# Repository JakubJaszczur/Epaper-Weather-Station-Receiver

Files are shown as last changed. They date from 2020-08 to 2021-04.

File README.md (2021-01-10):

## Epaper Weather Station Receiver

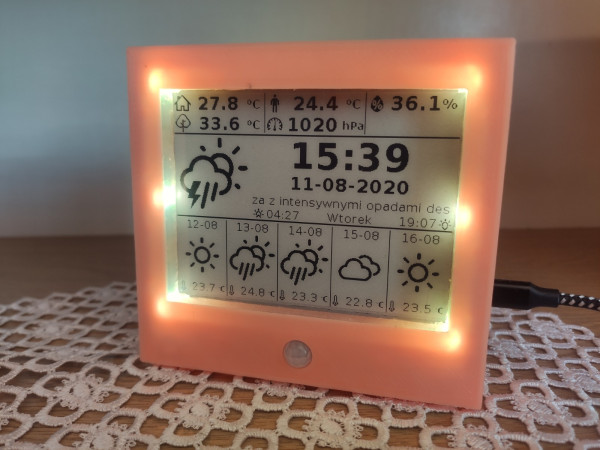
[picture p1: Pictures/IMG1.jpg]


### 1. Introduction

The project is a part of bigger IOT system. Weather Station receiver measures basic parameters, such as temperature, pressure, humidity, but also CO2, TVOC level. Other parameters, like outside temperature, weather forecast can be received by MQTT and displayed on 4.2" Epaper display.

### 2. Features

- 4.2" E-paper display with additional NeoPixel backlight
- Backlight colour depends on CO<sub>2</sub> in room
- Li-Ion battery as backup PS
- Additional fan for better air flow
- Temperature, humidity, pressure measurements
- CO<sub>2</sub>, TVOC level measurements
- PIR sensor
- Time, date, sunrise/sunset time display
- Current weather forecast with description
- Weather forecast for next 5 days
- Outside temperature, felt temperature display
- All displayed parameters/icons can be easily changed
- All not measured parameters are send to/from weather station by MQTT

### 3. Bill of Materials

Main components:

| Device  		 | Description 	 | Price		  | 
| --- | --- |---|
| ESP32 DEVKIT V1 | Main IC |	$3.50 |
| BME280 | Temperature, humidity, pressure sensor  |	$2.10 |
| MCP9808 | High accuracy temperature sensor | $0.75 |
| CCS811 | CO<sub>2</sub>, TVOC sensor | $5.89 |
| HC-SR505 | PIR sensor (AM312) | $1.15 |
| J5019 | Battery charger with DC-DC converter | $0.69 |
| 4.2" Epaper | Waveshare E-paper Display Module | $28.47 |
| 25mm fan | 5V fan (25x25x7mm) | $1.22 |
| SK6812 | RGBW NeoPixel LED | $0.25 |
| 1000mAh Li-Ion  | Battery | $2.50 |
| PCB | Custom PCB | |
| Housing | Custom housing (3D printed) | |

### 4. Libraries

- [GxEPD](https://github.com/ZinggJM/GxEPD "GxEPD")
- [Adafruit GFX](https://github.com/adafruit/Adafruit-GFX-Library "Adafruit_GFX")
- [PubSubClient](https://github.com/knolleary/pubsubclient "PubSubClient")
- [ArduinoJson](https://github.com/bblanchon/ArduinoJson "ArduinoJsonD")
- [Adafruit MCP9808](https://github.com/adafruit/Adafruit_MCP9808_Library "Adafruit_MCP9808")
- [Adafruit BME280](https://github.com/adafruit/Adafruit_BME280_Library "Adafruit_BME280")
- [Adafruit Sensor](https://github.com/adafruit/Adafruit_Sensor "Adafruit_Sensor")
- [Adafruit CCS811](https://github.com/adafruit/Adafruit_CCS811 "Adafruit_CCS811")
- [Adafruit NeoPixel](https://github.com/adafruit/Adafruit_NeoPixel "Adafruit_NeoPixel")

### 5. Getting Started

To run Weather Station, user should change some settings in data.h file:

Basic WiFi settings
```
// WiFi Settings
const char* ssid = "YOUR_SSID";
const char* password = "YOUR_PASSWORD";
```

Choose, how many NeoPixel LEDs you want to use. You can solder up to 10 LEDs. If you use less than 10, you should make shorts everywhere, where you do not use LEDs (Designators R2 to R7)
```
// NeoPixel settings
 ...
#define LED_COUNT   6       // No of LEDs
```

Uncomment, if you use MQTT user and password
```
// MQTT Settings
const char* mqtt_server = "MQTT_SERVER_IP";
//const char* mqtt_user = "MQTT_USER";
//const char* mqtt_password = "MQTT_PASSWORD";
```

You can adjust, how often display will be refreshed, and how often presence will be checked using PIR sensor (it also defines minimum backlight time)
```
// Refresh time in seconds
#define REFRESH_TIME	30
#define PRESENCE_TIME   5
```

Define altitude of your home (for pressure measurements)
```
// Sensors config data
#define ALTITUDE        515.0 //define altitude of location
```

Define MQTT Publish and Subscribe topics compatible with your server
```
// MQTT Input topics
#define TEMPOUT_TOPIC       "home/weatherstation/tempout"
#define TIME_TOPIC          "basic/time/time"
#define DATE_TOPIC          "basic/time/date"
#define SUNRISE_TOPIC       "conditions/weather/sunrise"
#define SUNSET_TOPIC        "conditions/weather/sunset"
#define DESCRIPTION_TOPIC   "conditions/weather/description"
#define WEEKDAY_TOPIC       "basic/time/day"
#define WEATHER_ICON_TOPIC  "conditions/weather/icon"
#define FELT_TEMP_TOPIC     "conditions/weather/tempfeel"
#define FORECAST1_TOPIC     "forecast1"
#define FORECAST2_TOPIC     "forecast2"
#define FORECAST3_TOPIC     "forecast3"
#define FORECAST4_TOPIC     "forecast4"
#define FORECAST5_TOPIC     "forecast5"

// MQTT Output topics
#define PUBLISH_TOPIC       "home/station"
```

### 6. Description

The main functionality of Weather Station is to measure inside conditions and display parameters on Epaper display.

#### Measurements
- <b>Temperature:</b> measured by MCP9808 to ensure high accuracy (0,25&ordm;C)
- <b>Humidity, Pressure:</b> measured by BME280
- <b>CO<sub>2</sub>, TVOC:</b> measured by CCS811
- <b>Presence:</b> measured by HC-SR505 PIR sensor, used to detect presence and to switch ON backlight
- <b>Other:</b> battery voltage can be measured using analog input

#### Display

Not all measured parameters are displayed on Epaper. I use only few most important indicators.

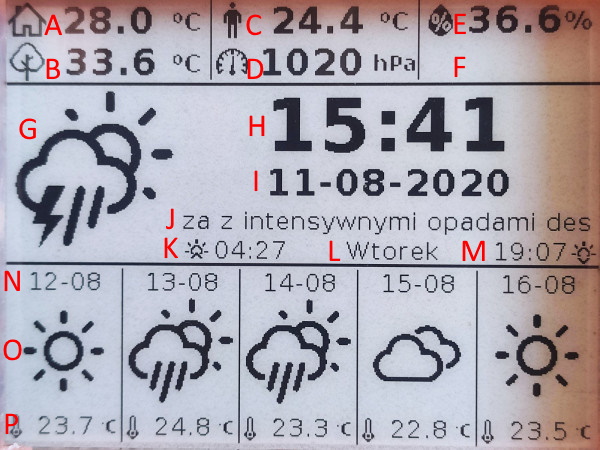
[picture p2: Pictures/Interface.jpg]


<b>A</b> Temperature inside (measured)<br>
<b>B</b> Temperature outside (MQTT)<br>
<b>C</b> Felt temperature (MQTT)<br>
<b>D</b> Pressure inside (measured)<br>
<b>E</b> Humidity inside (measured)<br>
<b>F</b> Empty space, to be used<br>
<b>G</b> Actual weather icon (MQTT)<br>
<b>H</b> Time (MQTT)<br>
<b>I</b> Date (MQTT)<br>
<b>J</b> Weather description (MQTT)<br>
<b>K</b> Sunrise time (MQTT)<br>
<b>L</b> Day of week (MQTT)<br>
<b>M</b> Sunset (MQTT)<br>
<b>N</b> Forecast date (MQTT)<br>
<b>O</b> Forecast icon (MQTT)<br>
<b>P</b> Forecast temperature (MQTT)

#### Input parameters

All MQTT subscribed topics should provide data in format:

| Topic  		  	| Type			 | Example	  		| Note				|
| --- 	| ---|---		|---		|
| TEMPOUT_TOPIC		| String								| 30.75				|					|
| TIME_TOPIC		| String								| 10:02				|					|
| DATE_TOPIC		| String								| 12-08-2020		|					|
| SUNRISE_TOPIC		| String								| 04:29				|					|
| SUNSET_TOPIC		| String								| 19:06				|					|
| DESCRIPTION_TOPIC	| String								| Sunny				|					|
| WEEKDAY_TOPIC		| String								| Monday			|					|
| WEATHER_ICON_TOPIC| String								| 1					| See picture below	|
| FELT_TEMP_TOPIC	| String								| 31.56				|					|
| FORECASTx_TOPIC	| JSON									| See example below |					|
| SERVICE_TOPIC | String | See service | |

Weather Icons codes

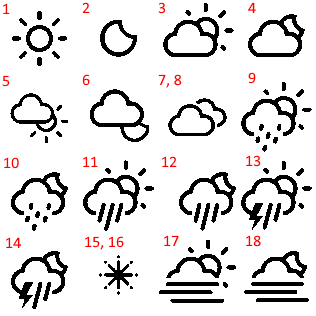
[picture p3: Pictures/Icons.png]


Forecast JSON example
```json
{
"time1":"12-08",
"icon1":"1",
"temp1":22.23
}
```

#### Output parameters

Parameters send by device in PUBLISH_TOPIC are in JSON format:

```json
{
"tempIn":24.7,
"humIn":44.9248,
"pressIn":1022.372,
"co2":1065,
"tvoc":101,
"bat":4.174172
}
```
#### Service commands

Some simple service commands can be send to Station using SERVICE_TOPIC:

RESTART - force ESP restart  
SENSORS - send sensors statuses, 1 if sensor was correctly initialized  
STATUS - send online time  

Feedback will be send in DEBUG_TOPIC

### 7. Changelog

2021-01-10 <b>V1.0</b> Stable version - little bit optimized, added STL files  
2020-08-25 <b>V0.1.5</b> Stable beta - not optimized, without STL files (Public)  
2020-08-11 <b>V0.1</b> First Beta Release - not optimized, without firmware code (private)

### 8. Task list

- Software:
- [X] Firmware code optimization
- [X] Service commands (sensors statuses, online time)
- [X] Battery voltage measurements

## 9. Pictures

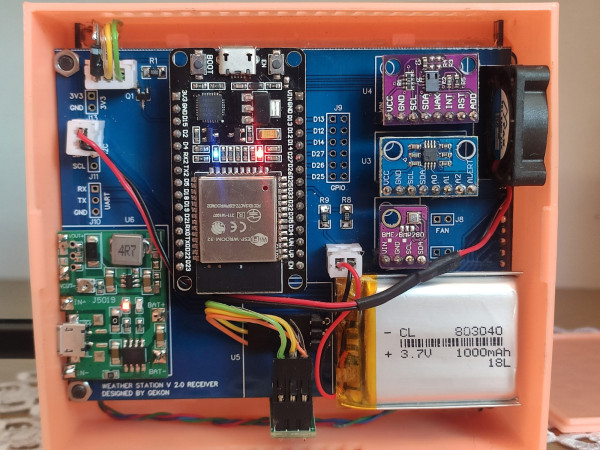
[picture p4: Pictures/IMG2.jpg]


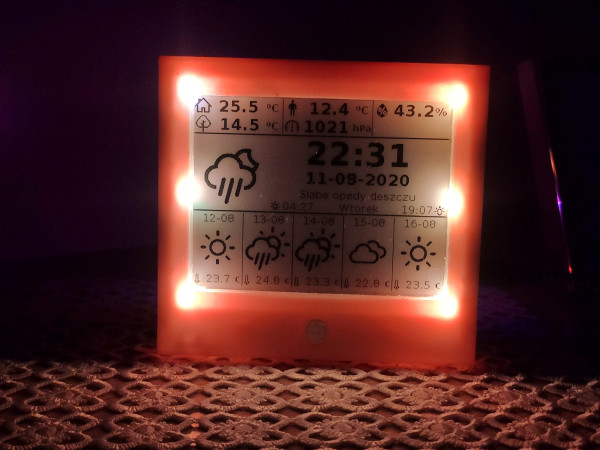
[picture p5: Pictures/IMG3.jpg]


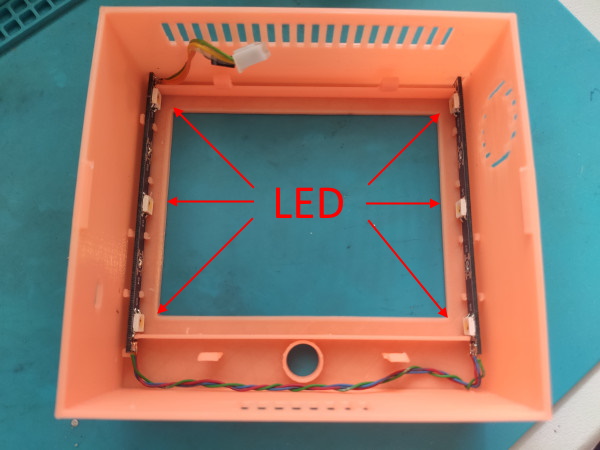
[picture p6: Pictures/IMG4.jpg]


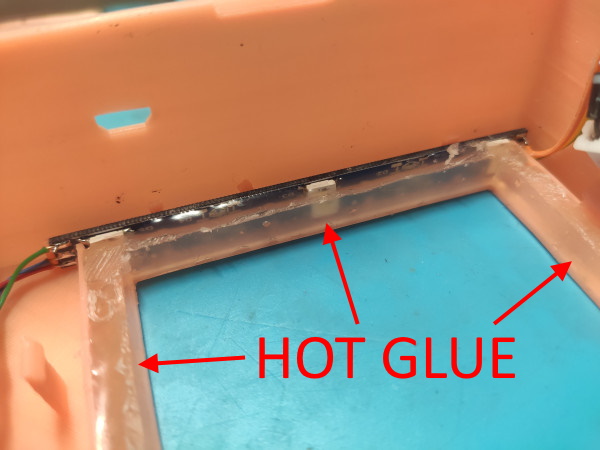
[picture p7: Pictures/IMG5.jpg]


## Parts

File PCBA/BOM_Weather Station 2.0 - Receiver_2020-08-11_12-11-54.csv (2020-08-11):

ID | Name | Designator | Footprint | Quantity | Manufacturer Part | Manufacturer | Supplier | Supplier Part | LCSC Assembly
1 | BME280 | U2 | BME280 | 1
2 | HC-SR505 | U5 | CON 3X1 PIN | 1
3 | J5019 | U6 | J5019 | 1
4 | SK6812 | D8,D7,D2,D1,D4,D9,D10,D3,D5,D6 | SK6812 | 10
5 | Header-Male-2.54_1x4 | J11 | CON 4X1 PIN | 1 | 210S-1*4P L=11.6MMGold-plated black | Ckmtw | LCSC | C124378
6 | 0R | R3,R2,R6,R5,R11,R7,R4,R10 | 0603 | 8
7 | Header-Male-2.54_1x3 | J10,J2 | CON 3X1 PIN | 2 | Header2.54mm 1*3P | BOOMELE | LCSC | C49257
8 | Header-Male-2.54_1x3 | J4,J6,J3,J5 | CON 3X1 PIN SMT | 4 | Header2.54mm 1*3P | BOOMELE | LCSC | C49257
9 | 2N7002K | Q1 | SOT-23-3_L2.9-W1.3-P1.90-LS2.4-BR | 1 | 2N7002K | Hottech | LCSC | C181083 | Yes
10 | MCP9808 | U3 | MCP9808 | 1
11 | 1N4148 | D11 | SOD-123_L2.8-W1.8-LS3.7-RD | 1 | FH1N4148W-JE | FH | LCSC | C105503
12 | 100k | R9 | 1206 | 1
13 | 330k | R8 | 1206 | 1
14 | 100R | R1,R12 | 1206 | 2
15 | Header-Female-2.54_1x8 | J1 | CON 8X1 PIN | 1 | Female headerHDR1X8-2.54 | BOOMELE | LCSC | C27438
16 | 210S-2*6P L=11.6MMGold-plated black | J9 | CON 6X2 PIN | 1 | 210S-2*6P L=11.6MMGold-plated black | Ckmtw | LCSC | C124388
17 | Header-Male-2.54_1x2 | J13,J8,J7,J12 | CON 2X1 PIN | 4 | 826629-2 | TE Connectivity | LCSC | C86471
18 | CCS811 | U4 | CCS811 | 1
19 | ESP32 DEVKIT V1 | U1 | ESP32 DEVKIT V1 DOIT | 1

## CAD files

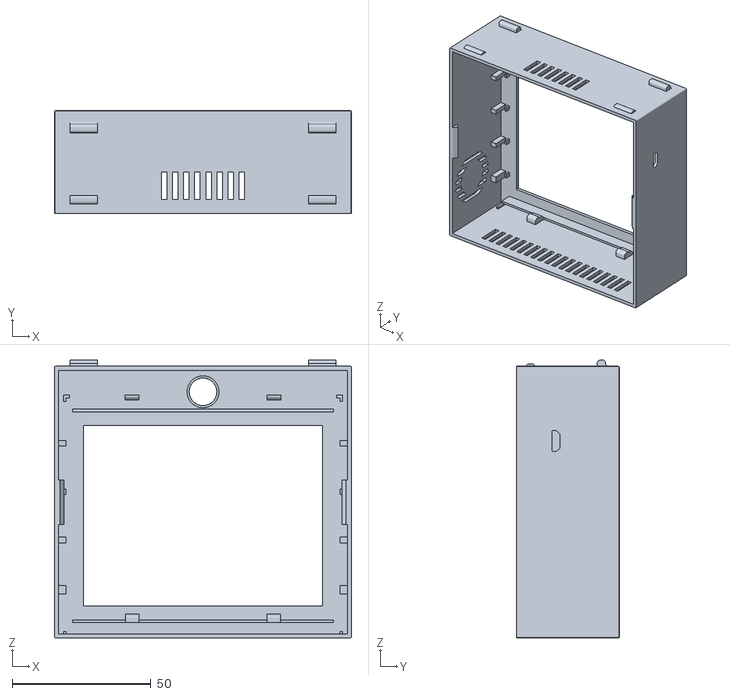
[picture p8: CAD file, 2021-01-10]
Mechanical/MainBody.stl
107.0 x 37.1 x 100.1

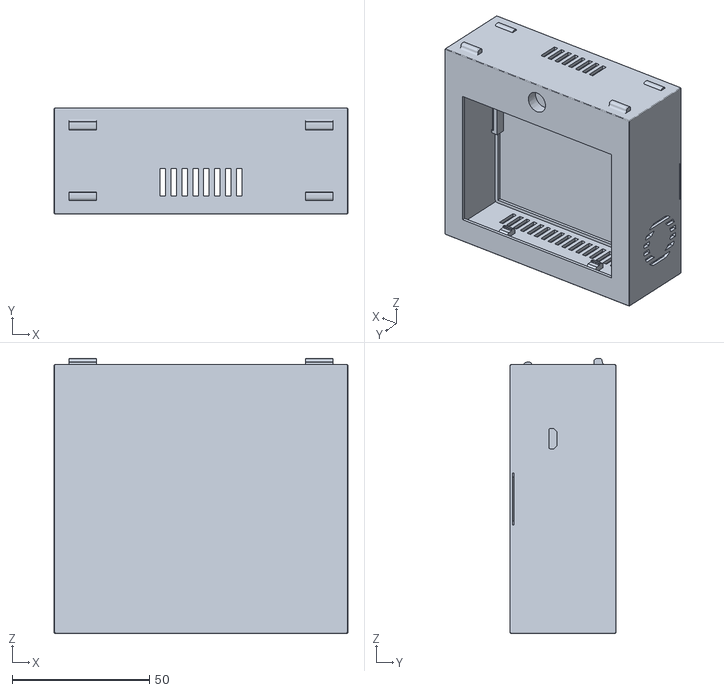
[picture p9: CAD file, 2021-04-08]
Mechanical/Housing.stl
107.0 x 38.6 x 100.1

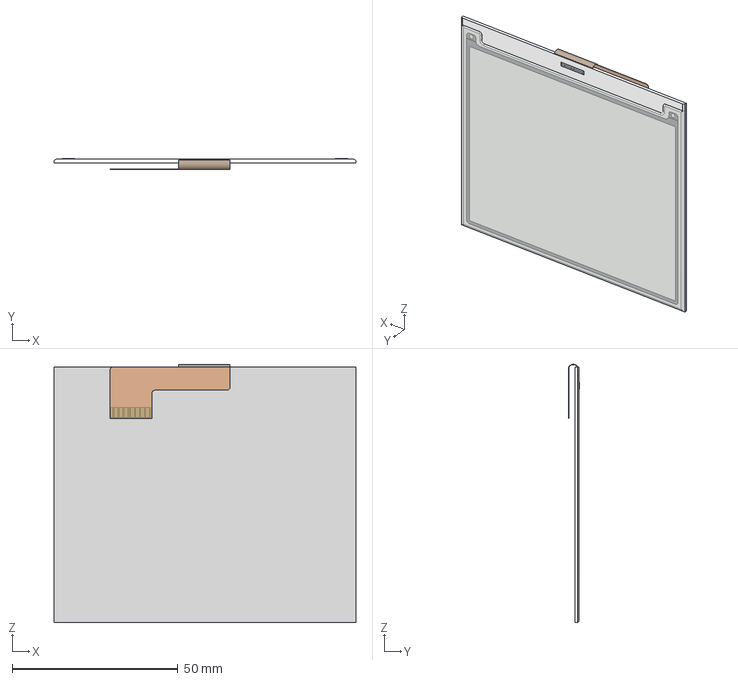
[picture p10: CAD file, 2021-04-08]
Mechanical/Waveshare 4.2 E-Ink - Display folded cable.step
91.0 x 3.17 x 77.9 mm

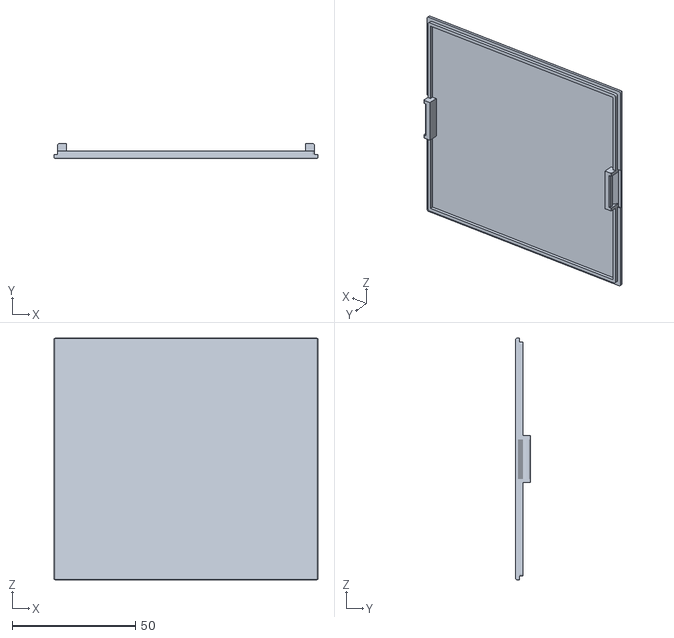
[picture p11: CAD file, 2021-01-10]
Mechanical/Cover.stl
107.0 x 6.00 x 97.9

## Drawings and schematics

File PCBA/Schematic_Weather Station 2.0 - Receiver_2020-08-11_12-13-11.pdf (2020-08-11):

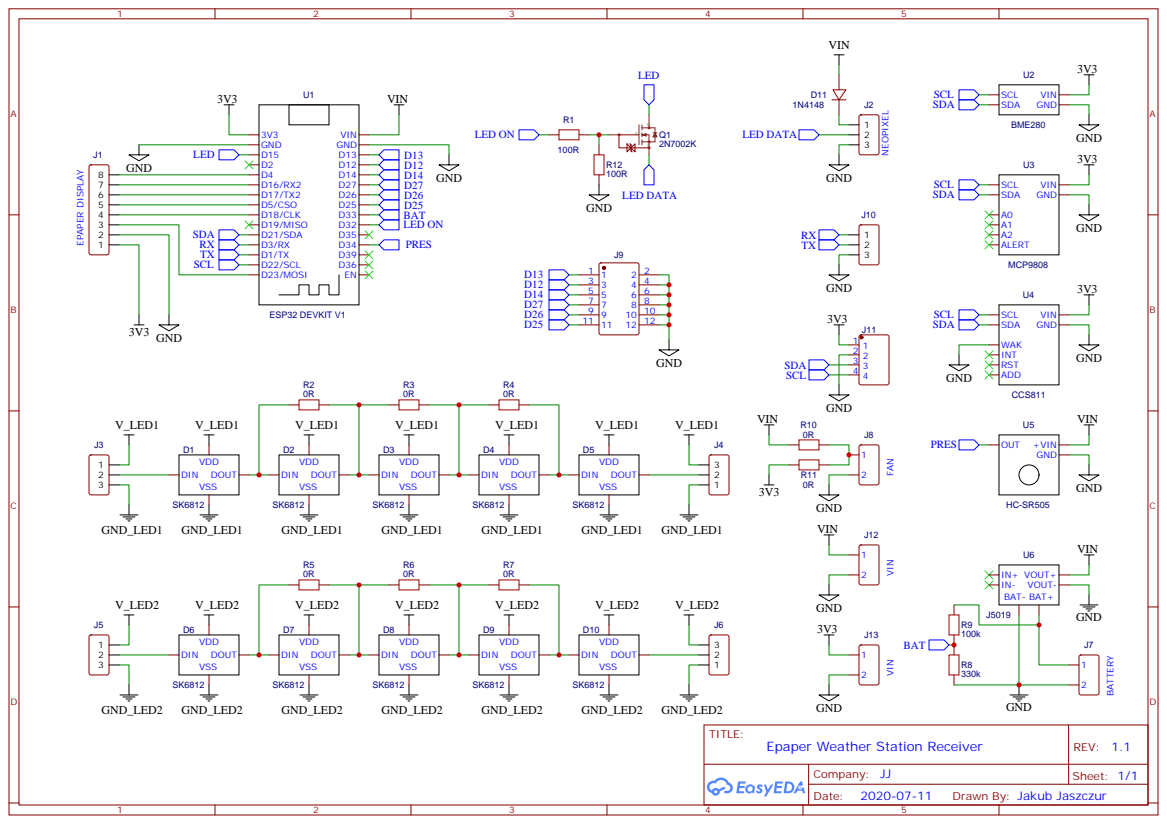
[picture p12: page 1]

Drawn By: Jakub Jaszczur

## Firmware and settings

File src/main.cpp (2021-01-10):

// ************************************* //
// ** Epaper Weather Station Receiver ** //
// ***** Version 1.0 ** 2021-01-10 ***** //
// ************************************* //

// 2021-01-10 Added service commands, optimalization
// 2020-08-25 Optimalization

#include <Arduino.h>
#include <GxEPD.h>
#include <GxGDEW042T2/GxGDEW042T2.h>      // 4.2" b/w
#include <GxIO/GxIO_SPI/GxIO_SPI.h>
#include <GxIO/GxIO.h>
#include <myFont.h>
#include <myBitmaps.h>
#include <data.h>
#include <WiFi.h>
#include <PubSubClient.h>
#include <ArduinoJson.h>
#include <Adafruit_NeoPixel.h>

// Sensors
#include <Wire.h>
#include "Adafruit_MCP9808.h"
#include <Adafruit_Sensor.h>
#include <Adafruit_BME280.h>
#include "Adafruit_CCS811.h"

Adafruit_MCP9808 tempsensor = Adafruit_MCP9808(); // temp
Adafruit_BME280 bme; // temp, hum, press
Adafruit_CCS811 ccs;  // CO2
Adafruit_NeoPixel strip(LED_COUNT, LED_PIN, NEO_GRBW + NEO_KHZ800);

// Eink - > ESP32 mapping:
// BUSY -> D4, RST -> RX2, DC -> TX2, CS -> D5, CLK -> D18, DIN -> D23, GND -> GND, VCC -> 3V3
GxIO_Class io(SPI, /*CS=5*/ SS, /*DC=*/ 17, /*RST=*/ 16); // arbitrary selection of 17, 16
GxEPD_Class display(io, /*RST=*/ 16, /*BUSY=*/ 4); // arbitrary selection of (16), 4

WiFiClient espClient;
PubSubClient client(espClient);

// Globals

// JSON object to keep data
const size_t capacity = JSON_OBJECT_SIZE(3) + 40;
DynamicJsonDocument doc(capacity);

float tempOut;
float tempFeel;

String timeToDisplay;
String dateToDisplay;
String sunriseTime;
String sunsetTime;
String weatherDescription;
String weekDay;

String forecastString;

int weatherIcon = 0;
int forecast1Icon = 0;
int forecast2Icon = 0;
int forecast3Icon = 0;
int forecast4Icon = 0;
int forecast5Icon = 0;

String date1 = "00-00";
String date2 = "00-00";
String date3 = "00-00";
String date4 = "00-00";
String date5 = "00-00";

float forecastTemp1;
float forecastTemp2;
float forecastTemp3;
float forecastTemp4;
float forecastTemp5;

bool MPC9808status = false;
bool BME280status = false;
bool CCS811status = false;

unsigned long startTime = 0;

// Battery measurement function

float measureBattery()
{
  int measurement = analogRead(BAT_PIN);
  float voltage = (((measurement / 4095.00) * VIN) / DIVIDER);

  return voltage;
}

// NeoPixel function

void colorWipe(uint32_t color)
{
  for(int i = 0; i < strip.numPixels(); i ++)
  {
    strip.setPixelColor(i, color);         //  Set pixel's color (in RAM)
    strip.show();                          //  Update strip to match
  }
}

void mapColours(int testVariable, int medLevel, int maxLevel, int colours[])
{
  if(testVariable <= medLevel)
    {
      /*Rcolor = map(testVariable, 0, medLevel, 0, 255);
      Gcolor = map(testVariable, 0, medLevel, 0, 255);
      Wcolor = map(testVariable, 0, medLevel, 255, 0);*/
      colours[0] = map(testVariable, 0, medLevel, 0, 255);
      colours[1] = map(testVariable, 0, medLevel, 0, 255);
      colours[3] = map(testVariable, 0, medLevel, 255, 0);
    }

  else
    {
      /*Rcolor = 255;
      Gcolor = map(testVariable, medLevel + 1, medLevel, 255, 0);
      Wcolor = 0;*/
      colours[0] = 255;
      colours[1] = map(testVariable, medLevel + 1, maxLevel, 255, 0);
      colours[3] = 0;
    }
}

// Checking presence

bool CheckPresence(int pinNo, bool lastStatus, bool mqttConnected)
{
  boolean status = digitalRead(pinNo);

  if((status != lastStatus) && (mqttConnected))
  {
    char msg[5];
    String tempString = String(status);

    tempString.toCharArray(msg, sizeof(msg));
    client.publish("home/presence", msg);
    Serial.println("Message sent!");
  }

  return status;
}

// MCP9808 functions

boolean InitialiseMPC9808(byte mode)
{
  if(!tempsensor.begin(MCP9808_ADDR))
  {
    Serial.println("MCP9808 Error");
    return false;
  }
  else
  {
    Serial.println("MCP9808 Initialised");
    tempsensor.setResolution(mode); // sets the resolution mode of reading, the modes are defined in the table bellow:
  // Mode Resolution SampleTime
  //  0    0.5°C       30 ms
  //  1    0.25°C      65 ms
  //  2    0.125°C     130 ms
  //  3    0.0625°C    250 ms
    return true;
  }
}

float GetTemperatureMCP9808()
{
  tempsensor.wake();   // wake up, ready to read!
  float temperature = tempsensor.readTempC() - 2.3;
  tempsensor.shutdown_wake(1); // shutdown MSP9808 - power consumption ~0.1 mikro Ampere, stops temperature sampling

  return temperature;
}

// BME280 functions

boolean InitialiseBME280()
{
  if (!bme.begin(BME280_ADDR, &Wire))
  //if (!bme.begin())
  {
    Serial.println("BME280 Error");
    return false;
  }
  else
  {
    Serial.println("BME280 Initialised");
    return true;
  }

}

float GetTemperatureBME280()
{
  float temperature = bme.readTemperature();

  return temperature;
}

float GetHumidityBME280()
{
  float humidity = bme.readHumidity();

  return humidity;
}

float GetPressureBME280()
{
  float pressure = bme.readPressure();
  pressure = bme.seaLevelForAltitude(ALTITUDE, pressure);
  pressure = pressure / 100.0F;

  return pressure;
}

// CCS811 functions

boolean InitialiseCCS811()
{
  if (!ccs.begin())
  {
    Serial.println("CCS811 Error");
    return false;
  }
  else
  {
    Serial.println("CCS811 Initialised");
    while(!ccs.available());
    return true;
  }

}

int GetCO2()
{
  int co2 = 0;

  if(ccs.available())
  {
    if(!ccs.readData())
    {
      co2 = ccs.geteCO2();
    }
    else
    {
      Serial.println("CO2 read error!");
    }
  }

  return co2;
}

int GetTVOC()
{
  int tvoc = ccs.getTVOC();

  return tvoc;
}

void SetEnvData(int humidity, double temperature)
{
  ccs.setEnvironmentalData(humidity, temperature);
}

// Eink functions

void showBackground()
{
  display.setRotation(0);
  // draw background
  display.drawExampleBitmap(background, 0, 0, 400, 300, GxEPD_BLACK);
  display.update();

  // partial update to full screen to preset for partial update of box window
  // (this avoids strange background effects)
  display.updateWindow(0, 0, 400, 300, false);
}

void displayIcon(int iconID)
{

  switch(iconID)
  {
    case 1:
    {
      display.drawExampleBitmap(d01, ICON_X, ICON_Y, ICON_W, ICON_H, GxEPD_BLACK);
      break;
    }
    case 2:
    {
      display.drawExampleBitmap(n01, ICON_X, ICON_Y, ICON_W, ICON_H, GxEPD_BLACK);
      break;
    }
    case 3:
    {
      display.drawExampleBitmap(d02, ICON_X, ICON_Y, ICON_W, ICON_H, GxEPD_BLACK);
      break;
    }
    case 4:
    {
      display.drawExampleBitmap(n02, ICON_X, ICON_Y, ICON_W, ICON_H, GxEPD_BLACK);
      break;
    }
    case 5:
    {
      display.drawExampleBitmap(d03, ICON_X, ICON_Y, ICON_W, ICON_H, GxEPD_BLACK);
      break;
    }
    case 6:
    {
      display.drawExampleBitmap(n03, ICON_X, ICON_Y, ICON_W, ICON_H, GxEPD_BLACK);
      break;
    }
    case 7:
    case 8:
    {
      display.drawExampleBitmap(d04, ICON_X, ICON_Y, ICON_W, ICON_H, GxEPD_BLACK);
      break;
    }
    case 9:
    {
      display.drawExampleBitmap(d09, ICON_X, ICON_Y, ICON_W, ICON_H, GxEPD_BLACK);
      break;
    }
    case 10:
    {
      display.drawExampleBitmap(n09, ICON_X, ICON_Y, ICON_W, ICON_H, GxEPD_BLACK);
      break;
    }
    case 11:
    {
      display.drawExampleBitmap(d10, ICON_X, ICON_Y, ICON_W, ICON_H, GxEPD_BLACK);
      break;
    }
    case 12:
    {
      display.drawExampleBitmap(n10, ICON_X, ICON_Y, ICON_W, ICON_H, GxEPD_BLACK);
      break;
    }
    case 13:
    {
      display.drawExampleBitmap(d11, ICON_X, ICON_Y, ICON_W, ICON_H, GxEPD_BLACK);
      break;
    }
    case 14:
    {
      display.drawExampleBitmap(n11, ICON_X, ICON_Y, ICON_W, ICON_H, GxEPD_BLACK);
      break;
    }
    case 15:
    case 16:
    {
      display.drawExampleBitmap(d13, ICON_X, ICON_Y, ICON_W, ICON_H, GxEPD_BLACK);
      break;
    }
    case 17:
    {
      display.drawExampleBitmap(d50, ICON_X, ICON_Y, ICON_W, ICON_H, GxEPD_BLACK);
      break;
    }
    case 18:
    {
      display.drawExampleBitmap(n50, ICON_X, ICON_Y, ICON_W, ICON_H, GxEPD_BLACK);
      break;
    }
    default:
    {
      display.drawExampleBitmap(na, ICON_X, ICON_Y, ICON_W, ICON_H, GxEPD_BLACK);
      break;
    }
  }
}

void displayForecastIcon(int field, int iconID)
{
  int positionX;

  switch(field)
  {
    case 1:
    {
      positionX = ICON1_X;
      break;
    }
    case 2:
    {
      positionX = ICON2_X;
      break;
    }
    case 3:
    {
      positionX = ICON3_X;
      break;
    }
    case 4:
    {
      positionX = ICON4_X;
      break;
    }
    case 5:
    {
      positionX = ICON5_X;
      break;
    }
    default:
    {
      positionX = ICON1_X;
      break;
    }
  }

  switch(iconID)
  {
    case 1:
    {
      display.drawExampleBitmap(small_d01, positionX, BOT_ICONS_Y, BOT_ICONS_W, BOT_ICONS_H, GxEPD_BLACK);
      break;
    }
    case 2:
    {
      display.drawExampleBitmap(small_n01, positionX, BOT_ICONS_Y, BOT_ICONS_W, BOT_ICONS_H, GxEPD_BLACK);
      break;
    }
    case 3:
    {
      display.drawExampleBitmap(small_d02, positionX, BOT_ICONS_Y, BOT_ICONS_W, BOT_ICONS_H, GxEPD_BLACK);
      break;
    }
    case 4:
    {
      display.drawExampleBitmap(small_n02, positionX, BOT_ICONS_Y, BOT_ICONS_W, BOT_ICONS_H, GxEPD_BLACK);
      break;
    }
    case 5:
    {
      display.drawExampleBitmap(small_d03, positionX, BOT_ICONS_Y, BOT_ICONS_W, BOT_ICONS_H, GxEPD_BLACK);
      break;
    }
    case 6:
    {
      display.drawExampleBitmap(small_n03, positionX, BOT_ICONS_Y, BOT_ICONS_W, BOT_ICONS_H, GxEPD_BLACK);
      break;
    }
    case 7:
    case 8:
    {
      display.drawExampleBitmap(small_d04, positionX, BOT_ICONS_Y, BOT_ICONS_W, BOT_ICONS_H, GxEPD_BLACK);
      break;
    }
    case 9:
    {
      display.drawExampleBitmap(small_d09, positionX, BOT_ICONS_Y, BOT_ICONS_W, BOT_ICONS_H, GxEPD_BLACK);
      break;
    }
    case 10:
    {
      display.drawExampleBitmap(small_n09, positionX, BOT_ICONS_Y, BOT_ICONS_W, BOT_ICONS_H, GxEPD_BLACK);
      break;
    }
    case 11:
    {
      display.drawExampleBitmap(small_d10, positionX, BOT_ICONS_Y, BOT_ICONS_W, BOT_ICONS_H, GxEPD_BLACK);
      break;
    }
    case 12:
    {
      display.drawExampleBitmap(small_n10, positionX, BOT_ICONS_Y, BOT_ICONS_W, BOT_ICONS_H, GxEPD_BLACK);
      break;
    }
    case 13:
    {
      display.drawExampleBitmap(small_d11, positionX, BOT_ICONS_Y, BOT_ICONS_W, BOT_ICONS_H, GxEPD_BLACK);
      break;
    }
    case 14:
    {
      display.drawExampleBitmap(small_n11, positionX, BOT_ICONS_Y, BOT_ICONS_W, BOT_ICONS_H, GxEPD_BLACK);
      break;
    }
    case 15:
    case 16:
    {
      display.drawExampleBitmap(small_d13, positionX, BOT_ICONS_Y, BOT_ICONS_W, BOT_ICONS_H, GxEPD_BLACK);
      break;
    }
    case 17:
    {
      display.drawExampleBitmap(small_d50, positionX, BOT_ICONS_Y, BOT_ICONS_W, BOT_ICONS_H, GxEPD_BLACK);
      break;
    }
    case 18:
    {
      display.drawExampleBitmap(small_n50, positionX, BOT_ICONS_Y, BOT_ICONS_W, BOT_ICONS_H, GxEPD_BLACK);
      break;
    }
    default:
    {
      display.drawExampleBitmap(small_na, positionX, BOT_ICONS_Y, BOT_ICONS_W, BOT_ICONS_H, GxEPD_BLACK);
      break;
    }
  }
}

void displayValue(float value, int field)
{
  display.setFont(&SansSerif_bold_24);
  display.setTextColor(GxEPD_BLACK);

  uint16_t box_x = 0;
  uint16_t box_y = 0;
  uint16_t box_w = 0;
  uint16_t box_h = TOP_TEXT_H;
  uint16_t cursor_y = 0;
  uint16_t cursor_x = 0;

  switch(field) //position
  {
    case 1:         //tempIn
    {
      box_x = TEMP_IN_X;
      box_y = TEMP_IN_Y;
      box_w = TEMP_IN_W;
      break;
    }
    case 2:         //tempOut
    {
      box_x = TEMP_OUT_X;
      box_y = TEMP_OUT_Y;
      box_w = TEMP_OUT_W;
      break;
    }
    case 3:         //tempFeel
    {
      box_x = TEMP_FEEL_X;
      box_y = TEMP_FEEL_Y;
      box_w = TEMP_FEEL_W;
      break;
    }
    case 4:         //pressureIn
    {
      box_x = PRESSURE_X;
      box_y = PRESSURE_Y;
      box_w = PRESSURE_W;
      break;
    }
    case 5:         //humidityIn
    {
      box_x = HUMIDITY_X;
      box_y = HUMIDITY_Y;
      box_w = HUMIDITY_W;
      break;
    }
    case 6:         // reserved
    {
      //box_x = ;
      //box_y = ;
      //box_w = ;
      break;
    }
  }

  switch(field) //spaces
  {
    case 1:   //temperatures
    case 2:
    case 3:
    {
      if(value >= 0 && value < 10)
        cursor_x = box_x + 16;
      else if((value >= 10) || (value < 0 && value > -10))
        cursor_x = box_x + 8;
      else
        cursor_x = box_x;
      break;
    }
    case 5:   //humidity
    {
      cursor_x = box_x + 2;
      break;
    }
    case 4:   //pressure
    {
      if(value > 1000)
        cursor_x = box_x;
      else if(value > 100)
        cursor_x = box_x + 16;
      else
        cursor_x = box_x + 48;
      break;
    }
  }

  display.fillRect(box_x, box_y, box_w, box_h, GxEPD_WHITE);
  cursor_y = box_y + box_h - 5;
  display.setCursor(cursor_x + 2, cursor_y);

  switch(field)   //display settings
  {
    case 1:
    case 2:
    case 3:
    case 5:
    {
      display.print(value, 1);
      break;
    }
    case 4:
    {
      display.print(value, 0);
      break;
    }
  }
}

void displayForecastTemperature(float value, int field)
{
  display.setFont(&SansSerif_plain_16);
  display.setTextColor(GxEPD_BLACK);

  uint16_t box_x = 0;
  uint16_t box_y = BOT_TEMP_Y;
  uint16_t box_w = BOT_TEMP_W;
  uint16_t box_h = BOT_TEMP_H;
  uint16_t cursor_y = 0;
  uint16_t cursor_x = 0;

  switch(field) //position
  {
    case 1:         //temp1
    {
      box_x = TEMP1_X;
      break;
    }
    case 2:         //temp2
    {
      box_x = TEMP2_X;
      break;
    }
    case 3:         //temp3
    {
      box_x = TEMP3_X;
      break;
    }
    case 4:         //temp4
    {
      box_x = TEMP4_X;
      break;
    }
    case 5:         //temp5
    {
      box_x = TEMP5_X;
      break;
    }
  }

  display.fillRect(box_x, box_y, box_w, box_h, GxEPD_WHITE);
  cursor_y = box_y + box_h - 5;

  if(value >= 0 && value < 10)
    cursor_x = box_x + 10;
  else if((value >= 10) || (value < 0 && value > -10))
    cursor_x = box_x + 5;
  else
    cursor_x = box_x;

  display.setCursor(cursor_x + 2, cursor_y);

  display.print(value, 1);
}

void displayText(String text, int field)
{
  display.setFont(&SansSerif_plain_16);
  display.setTextColor(GxEPD_BLACK);

  uint16_t box_x = 0;
  uint16_t box_y = 0;
  uint16_t box_w = 0;
  uint16_t box_h = MIDDLE_TEXT_H;
  uint16_t cursor_y = 0;
  uint16_t cursor_x = 0;
  float fontWidth = 9.5;  //average font width

  switch(field)
  {
    case 1:         //sunrise
    {
      box_x = SUNRISE_X;
      box_y = SUNRISE_Y;
      box_w = SUNRISE_W;
      cursor_x = box_x + 2;
      break;
    }
    case 2:         //sunset
    {
      box_x = SUNSET_X;
      box_y = SUNSET_Y;
      box_w = SUNSET_W;
      cursor_x = box_x + 2;
      break;
    }
    case 3:         //weather description
    {
      box_x = DESCR_X;
      box_y = DESCR_Y;
      box_w = DESCR_W;
      cursor_x = (uint16_t)(box_x + (box_w - text.length() * fontWidth) / 2);
      break;
    }
    case 4:         //week day
    {
      box_x = DAY_X;
      box_y = DAY_Y;
      box_w = DAY_W;
      cursor_x = (uint16_t)(box_x + (box_w - text.length() * fontWidth) / 2);
      break;
    }
    case 5:         //date 1
    {
      box_x = DATE1_X;
      box_y = BOT_DATE_Y;
      box_w = BOT_DATE_W;
      cursor_x = (uint16_t)(box_x + (box_w - text.length() * fontWidth) / 2);
      break;
    }
    case 6:         //date 2
    {
      box_x = DATE2_X;
      box_y = BOT_DATE_Y;
      box_w = BOT_DATE_W;
      cursor_x = (uint16_t)(box_x + (box_w - text.length() * fontWidth) / 2);
      break;
    }
    case 7:         //date 3
    {
      box_x = DATE3_X;
      box_y = BOT_DATE_Y;
      box_w = BOT_DATE_W;
      cursor_x = (uint16_t)(box_x + (box_w - text.length() * fontWidth) / 2);
      break;
    }
    case 8:         //date 4
    {
      box_x = DATE4_X;
      box_y = BOT_DATE_Y;
      box_w = BOT_DATE_W;
      cursor_x = (uint16_t)(box_x + (box_w - text.length() * fontWidth) / 2);
      break;
    }
    case 9:         //date 5
    {
      box_x = DATE5_X;
      box_y = BOT_DATE_Y;
      box_w = BOT_DATE_W;
      cursor_x = (uint16_t)(box_x + (box_w - text.length() * fontWidth) / 2);
      break;
    }
  }

  display.fillRect(box_x, box_y, box_w, box_h, GxEPD_WHITE);
  cursor_y = box_y + box_h - 3;
  display.setCursor(cursor_x, cursor_y);
  display.print(text);
  //display.updateWindow(box_x, box_y, box_w, box_h, false);
}

void displayTime(String tempTime)
{
  display.setFont(&SansSerif_bold_50);
  display.setTextColor(GxEPD_BLACK);

  uint16_t box_x = TIME_X;
  uint16_t box_y = TIME_Y;
  uint16_t box_w = TIME_W;
  uint16_t box_h = TIME_H;
  uint16_t cursor_y = box_y + box_h - 6;;

  display.fillRect(box_x, box_y, box_w, box_h, GxEPD_WHITE);
  display.setCursor(box_x + 2, cursor_y);
  display.print(tempTime);
  //display.updateWindow(box_x, box_y, box_w, box_h, false);
}

void displayDate(String tempDate)
{
  display.setFont(&SansSerif_bold_24);
  display.setTextColor(GxEPD_BLACK);

  uint16_t box_x = DATE_X;
  uint16_t box_y = DATE_Y;
  uint16_t box_w = DATE_W;
  uint16_t box_h = DATE_H;
  uint16_t cursor_y = box_y + box_h - 6;

  display.fillRect(box_x, box_y, box_w, box_h, GxEPD_WHITE);
  display.setCursor(box_x + 2, cursor_y);
  display.print(tempDate);
  //display.updateWindow(box_x, box_y, box_w, box_h, false);
}

// WiFi setup

void setupWifi()
{
  delay(10);
  // We start by connecting to a WiFi network
  Serial.println();
  Serial.print("Connecting to ");
  Serial.println(ssid);

  WiFi.begin(ssid, password);
  WiFi.setHostname(DEVICE_NAME);
  delay(100);

  while (WiFi.status() != WL_CONNECTED)
  {
    delay(500);
    Serial.print(".");
  }

  randomSeed(micros());

  Serial.println("");
  Serial.println("WiFi connected");
  Serial.println("IP address: ");
  Serial.println(WiFi.localIP());
}

bool wifiConnectionStatus(int counter)
{
  bool status = false;

  for(int i = 0; i < counter; i++)  //try to reconnect x times
  {
    if(WiFi.isConnected())
    {
      status = true;
      break;
    }
    else
    {
      delay(500);
      WiFi.reconnect();
      status = WiFi.isConnected();
      if(status)
        break;
    }
  }

  return status;
}

// SERVICE HANDLE

String checkOnlineTime()
{
  unsigned long actualTime = millis() / 1000;
  unsigned long onlineTime = actualTime - (startTime / 1000);

  int days = onlineTime / 86400;
  int hours = (onlineTime - days * 86400) / 3600;
  int minutes = (onlineTime - days * 86400 - hours * 3600) / 60;

  return String(days) + " d " + String(hours) + " h " + String(minutes) + " min";
}
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
void loop()
{
  unsigned long timeNow;
  static unsigned long timeLast;
  static unsigned long timeLastPresence;

  static float tempIn = 0;
  static float humIn = 0;
  static float pressIn = 0;

  static int co2 = 0;
  static int tvoc = 0;

  static float battery = 0;

  static bool presenceStatus = false;
  static int rgbw[4] = {0};     // colours array for NEOPIXEL

  timeNow = millis();

  bool wifiStatus = wifiConnectionStatus(5);              // Check WiFI status and try to reconnect in case of no connection
  bool mqttStatus = MQTTconnectionStatus(wifiStatus, 5);  // Check MQTT status and try to reconnect in case of no connection
    
  client.loop();

  if((timeNow - timeLastPresence) > PRESENCE_TIME * 1000) // Get Presence and send is MQTT is available
  {
    presenceStatus = CheckPresence(PRESENCE_PIN, presenceStatus, mqttStatus);
    timeLastPresence = timeNow;
  }

  if((timeNow - timeLast) > REFRESH_TIME * 1000)          // Get data
  {
    if(MPC9808status)
      tempIn = GetTemperatureMCP9808();
    if(BME280status)
    {
      humIn = GetHumidityBME280();
      pressIn = GetPressureBME280();
    }
    if(CCS811status)
    {
      co2 = GetCO2();
      tvoc = GetTVOC();
    }

    battery = measureBattery();

    SetEnvData((int)humIn, (double)tempIn);

    if(mqttStatus)  // Send data only if device is connected to MQTT
    {
      sendDataMQTT(tempIn, humIn, pressIn, co2, tvoc, battery);
    }

    display.drawExampleBitmap(background, 0, 0, 400, 300, GxEPD_BLACK);
    displayValue(tempIn, 1);
    displayValue(tempOut, 2);
    displayValue(tempFeel, 3);
    displayValue(pressIn, 4);
    displayValue(humIn, 5);

    displayTime(timeToDisplay);
    displayDate(dateToDisplay);
    displayText(sunriseTime, 1);
    displayText(sunsetTime, 2);
    displayText(weatherDescription, 3);
    displayText(weekDay, 4);

    displayIcon(weatherIcon);
    displayForecastIcon(1, forecast1Icon);
    displayForecastIcon(2, forecast2Icon);
    displayForecastIcon(3, forecast3Icon);
    displayForecastIcon(4, forecast4Icon);
    displayForecastIcon(5, forecast5Icon);

    displayText(date1, 5);
    displayText(date2, 6);
    displayText(date3, 7);
    displayText(date4, 8);
    displayText(date5, 9);

    displayForecastTemperature(forecastTemp1, 1);
    displayForecastTemperature(forecastTemp2, 2);
    displayForecastTemperature(forecastTemp3, 3);
    displayForecastTemperature(forecastTemp4, 4);
    displayForecastTemperature(forecastTemp5, 5);

    display.update();

    timeLast = timeNow;
  }

  if(digitalRead(PRESENCE_PIN))            // Turn on backlight
  {
    digitalWrite(LED_ON, HIGH);
    mapColours(co2, MED_CO2, MAX_CO2, rgbw);

    colorWipe(strip.Color(rgbw[0], rgbw[1], rgbw[2], rgbw[3])); // RGBW
    //strip.setBrightness(BRIGHTNESS); // Set BRIGHTNESS to about 1/5 (max = 255)
    strip.show();                          //  Update strip to match
  }
  else
  {
    colorWipe(strip.Color(0, 0, 0, 0)); // RGBW
    digitalWrite(LED_ON, LOW);
    strip.show();                          //  Update strip to match
  }
}

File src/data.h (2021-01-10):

// WiFi Settings
const char* ssid = "";
const char* password = "";

#define DEVICE_NAME "WeatherStation"

// Battery measurement settings

#define BAT_PIN     33
#define VIN         3.28
#define DIVIDER     0.7674   // R1/(R1+R2)

// NeoPixel settings

#define LED_PIN     15
#define LED_ON      32
#define LED_COUNT   6       // No of LEDs
#define BRIGHTNESS  32     // NeoPixel brightness, 0 (min) to 255 (max)
#define MED_CO2     1500    // Poziom dyskomfortu
#define MAX_CO2     5000    // Max poziom

// MQTT Settings
const char* mqtt_server = "192.168.0.113";
const char* mqtt_user = "mqttuser";
const char* mqtt_password = "";

#define MQTT_MAX_PACKET_SIZE 256

// Refresh time in seconds
#define REFRESH_TIME	30
#define PRESENCE_TIME   5

// Sensors config data
#define ALTITUDE        515.0 //define altitude of location
#define BME280_ADDR     0x76 //BME280 I2C Address
#define MCP9808_ADDR    0x18
#define CCS811_ADDR     0x5A    // 0x5A or 0x5B

#define PRESENCE_PIN    34

// I2C settings
#define BME_SCK         22 //SCL
//#define BME_MISO 12//
//#define BME_MOSI 11//
#define BME_CS          21  //SDA

// Top text positions
#define TOP_TEXT_H      28

#define TEMP_IN_X		28
#define TEMP_IN_Y		0
#define TEMP_IN_W		80

#define TEMP_OUT_X		30
#define TEMP_OUT_Y		28
#define TEMP_OUT_W		80

#define TEMP_FEEL_X		170
#define TEMP_FEEL_Y		0
#define TEMP_FEEL_W		80

#define PRESSURE_X		170
#define PRESSURE_Y		28
#define PRESSURE_W		80

#define HUMIDITY_X		308
#define HUMIDITY_Y		0
#define HUMIDITY_W		45

// Middle objects positions
#define ICON_X			0
#define ICON_Y			58
#define ICON_W			120
#define ICON_H			120

#define TIME_X			175
#define TIME_Y			58
#define TIME_W			170
#define TIME_H			50

#define DATE_X			175
#define DATE_Y			108
#define DATE_W			170
#define DATE_H			30

#define MIDDLE_TEXT_H	20

#define DESCR_X			120
#define DESCR_Y			138
#define DESCR_W			280

#define SUNRISE_X		140
#define SUNRISE_Y		158
#define SUNRISE_W		50

#define SUNSET_X		328 //330
#define SUNSET_Y		158
#define SUNSET_W		50

#define DAY_X			200
#define DAY_Y			158
#define DAY_W			120

// Bottom objects positions
#define BOT_DATE_Y		180
#define BOT_DATE_W		79
#define BOT_DATE_H		20

#define DATE1_X			0
#define DATE2_X			80
#define DATE3_X			160
#define DATE4_X			240
#define DATE5_X			320

#define BOT_ICONS_Y		200
#define BOT_ICONS_W		79
#define BOT_ICONS_H		79

#define ICON1_X			0
#define ICON2_X			80
#define ICON3_X			160
#define ICON4_X			240
#define ICON5_X			320

#define BOT_TEMP_Y		280
#define BOT_TEMP_W		50
#define BOT_TEMP_H		20

#define TEMP1_X			15
#define TEMP2_X			95
#define TEMP3_X			175
#define TEMP4_X			255
#define TEMP5_X			335

// MQTT Input topics
#define TEMPOUT_TOPIC       "home/weatherstation/tempout"
#define TIME_TOPIC          "basic/time/time"
#define DATE_TOPIC          "basic/time/date"
#define SUNRISE_TOPIC       "conditions/weather/sunrise"
#define SUNSET_TOPIC        "conditions/weather/sunset"
#define DESCRIPTION_TOPIC   "conditions/weather/description"
#define WEEKDAY_TOPIC       "basic/time/day"
#define WEATHER_ICON_TOPIC  "conditions/weather/icon"
#define FELT_TEMP_TOPIC     "conditions/weather/tempfeel"
#define FORECAST1_TOPIC     "forecast1"
#define FORECAST2_TOPIC     "forecast2"
#define FORECAST3_TOPIC     "forecast3"
#define FORECAST4_TOPIC     "forecast4"
#define FORECAST5_TOPIC     "forecast5"
<<<<<<< HEAD:src/data.h

// MQTT Output topics
#define PUBLISH_TOPIC       "home/station"
=======
#define SERVICE_TOPIC       "home/weatherstation/service"

// MQTT Output topics
#define PUBLISH_TOPIC       "home/station"
#define DEBUG_TOPIC         "home/weatherstation/debug"
>>>>>>> Unstable:Software/src/data.h

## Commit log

2020-08-11 Added PCBA files
    [BOM_Weather Station 2.0 - Receiver_2020-08-11_12-11-54.csv]
2021-01-10 Added mechanical design, updated readme file
    [Cover.stl, MainBody.stl]
2021-04-08 Add mechanical parts
    [Housing.stl, Waveshare 4.2 E-Ink - Display folded cable.step]
